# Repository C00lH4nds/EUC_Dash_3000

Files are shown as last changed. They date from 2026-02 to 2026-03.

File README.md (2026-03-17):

# EUC_Dash_3000
ESP32 based dashboard for BEGODE EUC.

WARNING: Works only with Begode A2!

Displays: current speed, wheel battery percentage, temperature, distance, onboard battery level, light status, connexion status.

Capture d'écran 2026-02-22 011819

Capture d'écran 2026-02-22 011900

Designed to be mounted on Gyroriderz glove.

Huge thanks to WheelAndroid for publishing BLE message coding (https://github.com/Wheellog/Wheellog.Android)

!!!WARNING!!!
Onboard battery can burn or explode if short circuited. Pay attention to connexions and waterthightness.
You might want to add a BMS to avoid risk.
As we are messing with the wheel BLE messages there is a tiny risk to generate a cut off.

BOM:
ESP32 C3 Supermini: https://fr.aliexpress.com/item/1005009040816248.html

0.96 inch OLED screen: https://fr.aliexpress.com/item/1005006141235306.html

3.3V buck&boost converter: https://fr.aliexpress.com/item/1005008602719818.html

Battery connectors: scavenge from broken gadget or from https://fr.aliexpress.com/item/4001192853672.html

18350 battery: https://www.lepetitvapoteur.com/fr/accus/8325-accu-mxjo-18350-700mah.html

M2 screws: https://fr.aliexpress.com/item/1005006187019546.html

Screen protector: scavenge from blister package

Heatshrink tubing

Electronic wires

Cyanoacrylate glue to secure tubing on the case

Neoprene glue for screen protector

TPU and PLA (or PETG)

Wiring diagram:

Capture d'écran 2026-02-17 215041

Component placement:

Capture d'écran 2026-02-22 011713

All components should lock in place. OLED screen uses four optional screws with printed washers.
Clip the two bottom pins of the switches.

Printed case:

Capture d'écran 2026-02-22 011242

Print in 0.2mm layers. No supports.
TPU parts have "TPU" prefix. Other parts can be printed in PLA or PETG.

Glue the screen protector to system case cover with neoprene glue. Make sure it is watertight.

Capture d'écran 2026-02-22 020949

Mount everytinhg, put the glove on, gently heat the honeycomb part with a heatgun and bend the button box so it rests on the top of your thumb joint (it is always better than printing with supports!)

Battery goes below the top strap. Don't set it too tight.

Left button: double beep.
Middle button: ON/OFF. hold 5 seconds to turn off (deepsleep mode). Wheel connection is automatic at startup or if connexion is lost.
Right button: light ON/OFF.

Happy ride!
Subscribe to my channel: https://www.youtube.com/@OIGLabs

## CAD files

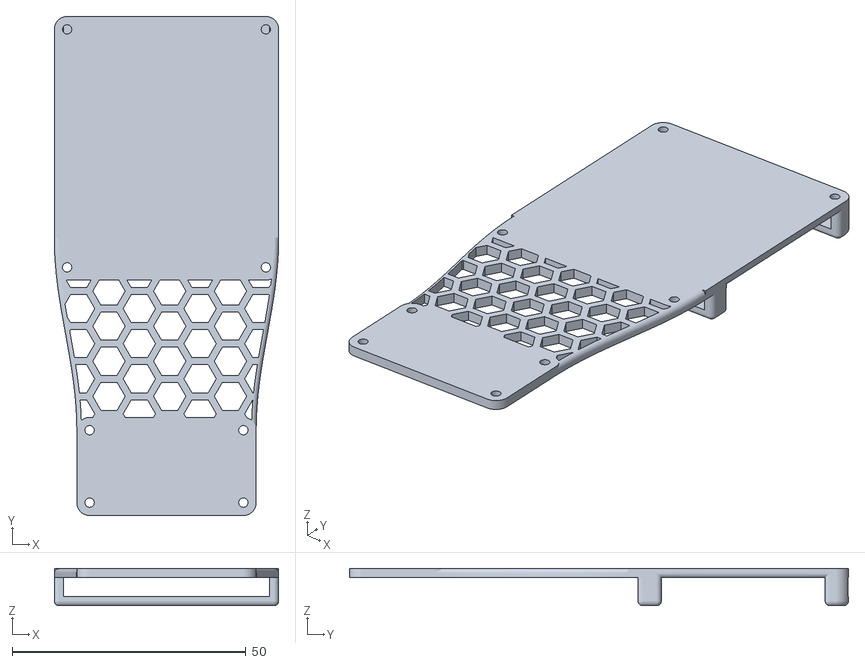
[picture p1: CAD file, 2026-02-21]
Stl/EUC Dash 3000_EUC Dash 3000 v37_System case_1_Support plate - straight.stl
48.0 x 106.7 x 8.00

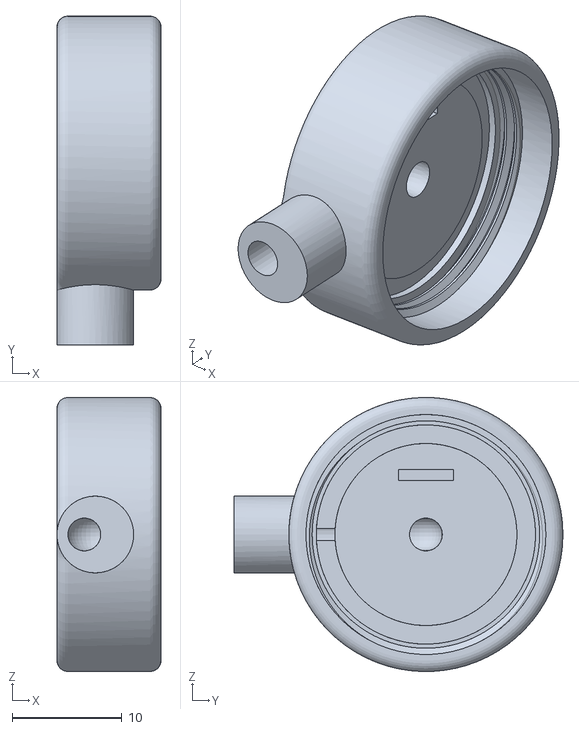
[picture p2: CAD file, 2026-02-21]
Stl/EUC Dash 3000_EUC Dash 3000 v37_Battery box_1_Battery box cap - negative.stl
9.50 x 30.0 x 25.0

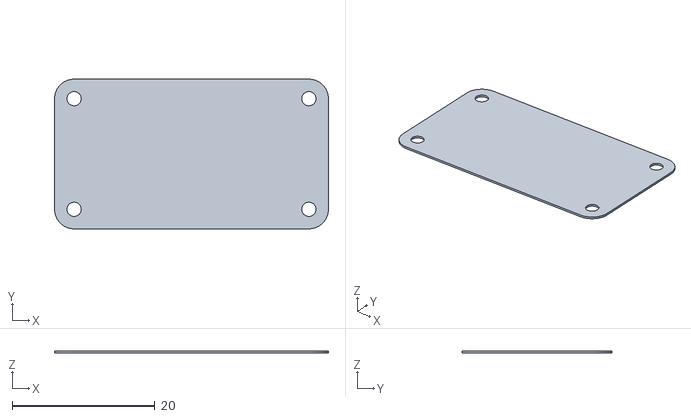
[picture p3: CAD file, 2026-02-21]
Stl/EUC Dash 3000_EUC Dash 3000 v37_Button box_1_TPU Button box gasket.stl
38.4 x 21.0 x 0.3

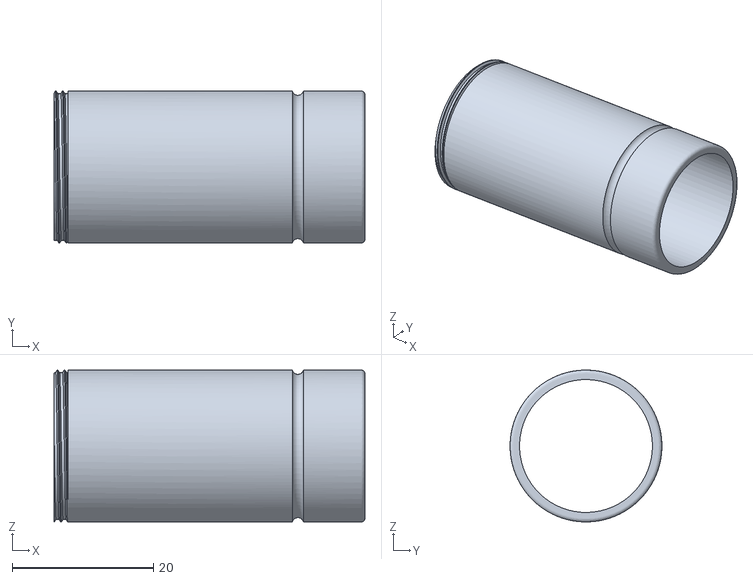
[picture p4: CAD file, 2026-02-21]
Stl/EUC Dash 3000_EUC Dash 3000 v37_Battery box_1_Battery box.stl
44.0 x 21.5 x 21.5

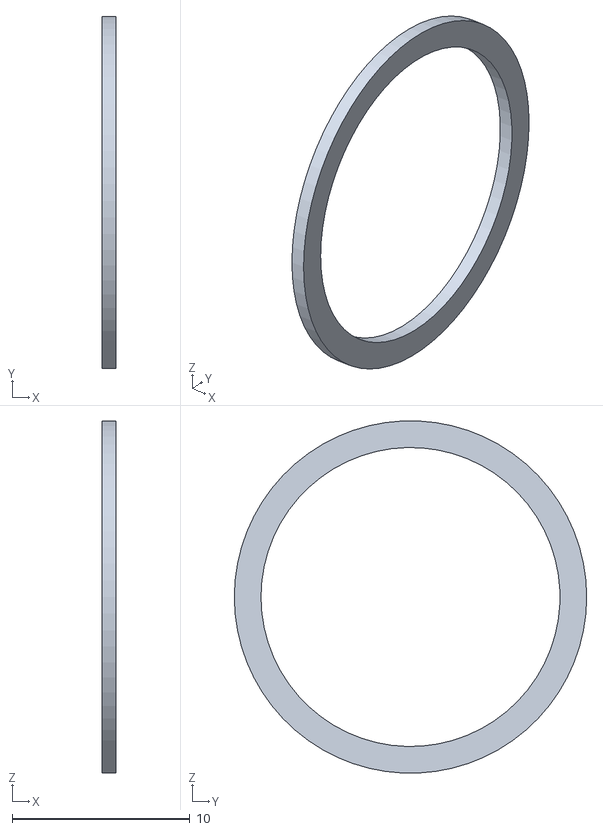
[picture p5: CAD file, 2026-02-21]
Stl/EUC Dash 3000_EUC Dash 3000 v37_Battery box_1_TPU gasket.stl
0.8 x 19.8 x 19.8

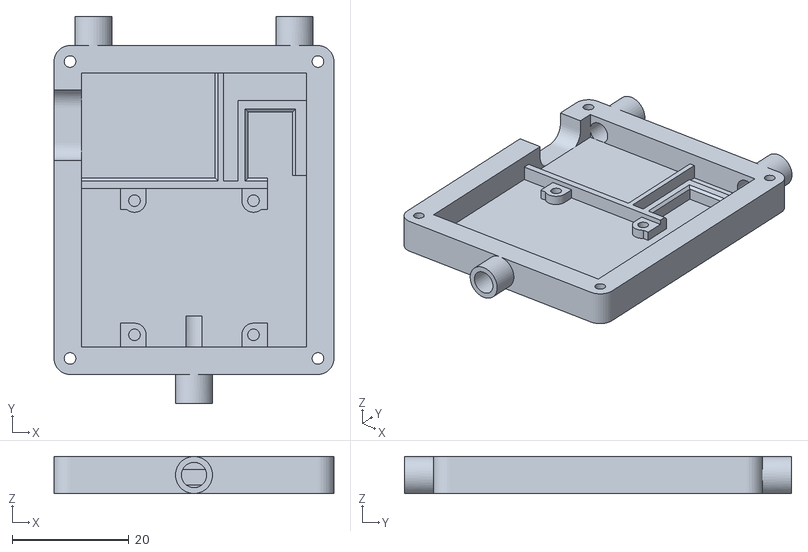
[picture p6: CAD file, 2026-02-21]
Stl/EUC Dash 3000_EUC Dash 3000 v37_System case_1_System box.stl
48.0 x 66.4 x 6.35

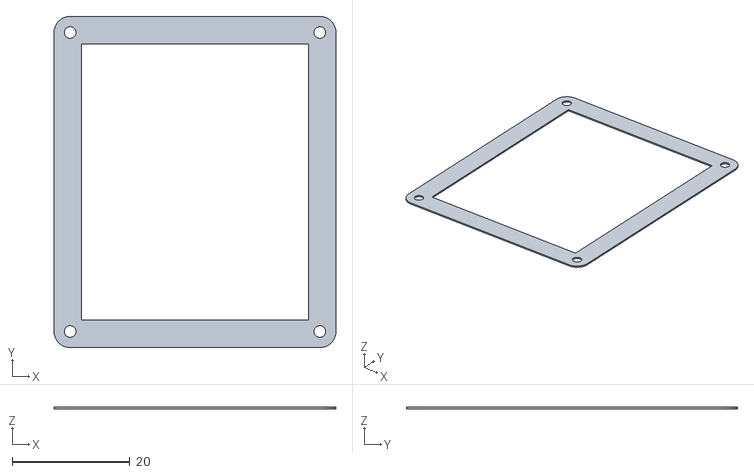
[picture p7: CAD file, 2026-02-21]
Stl/EUC Dash 3000_EUC Dash 3000 v37_System case_1_TPU System box gasket.stl
48.0 x 56.4 x 0.3

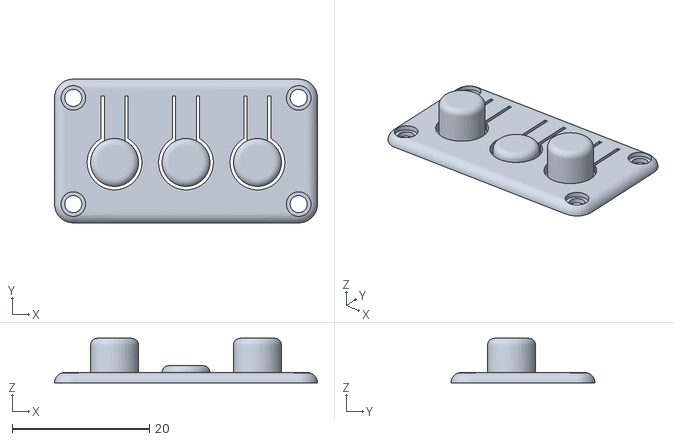
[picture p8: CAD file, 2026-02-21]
Stl/EUC Dash 3000_EUC Dash 3000 v37_Button box_1_Button box cover.stl
38.4 x 21.0 x 6.50

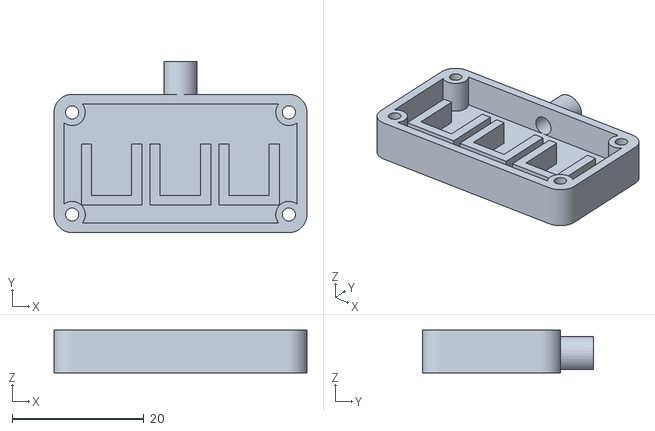
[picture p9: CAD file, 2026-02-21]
Stl/EUC Dash 3000_EUC Dash 3000 v37_Button box_1_Button box.stl
38.4 x 26.0 x 6.50

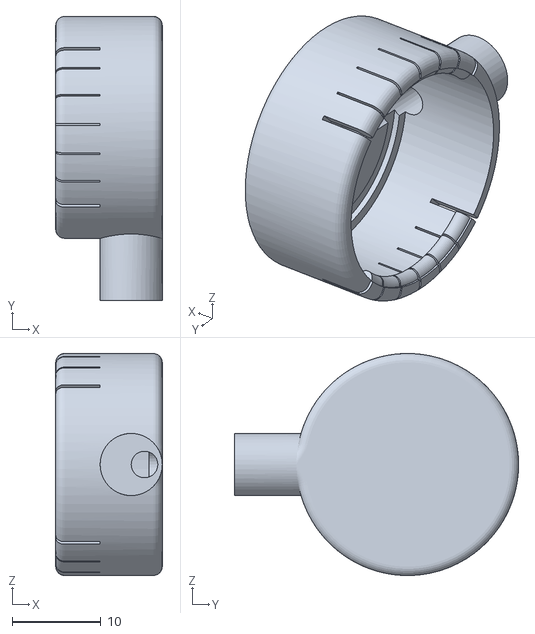
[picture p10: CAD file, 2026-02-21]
Stl/EUC Dash 3000_EUC Dash 3000 v37_Battery box_1_TPU Battery box cap - postive.stl
12.0 x 32.0 x 25.0

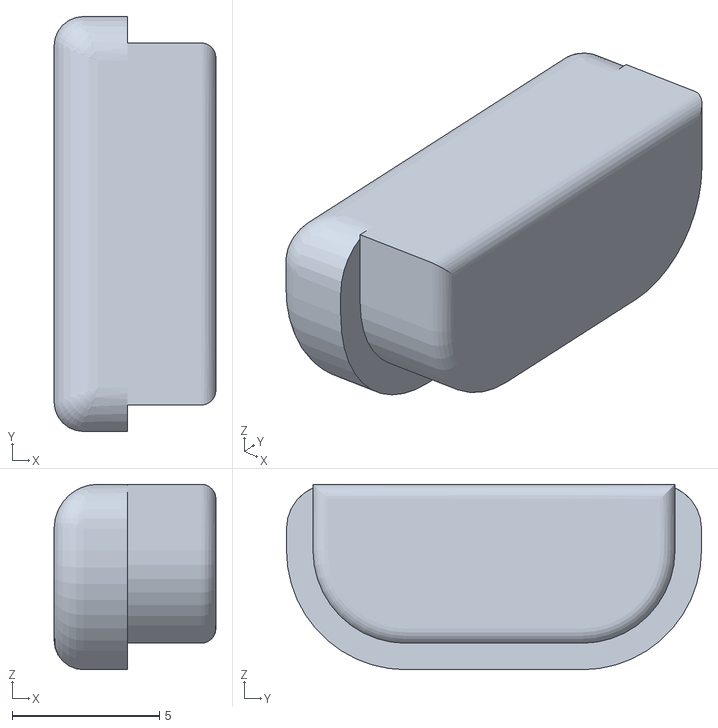
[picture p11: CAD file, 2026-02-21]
Stl/EUC Dash 3000_EUC Dash 3000 v37_System case_1_USB plug.stl
5.50 x 14.1 x 6.30

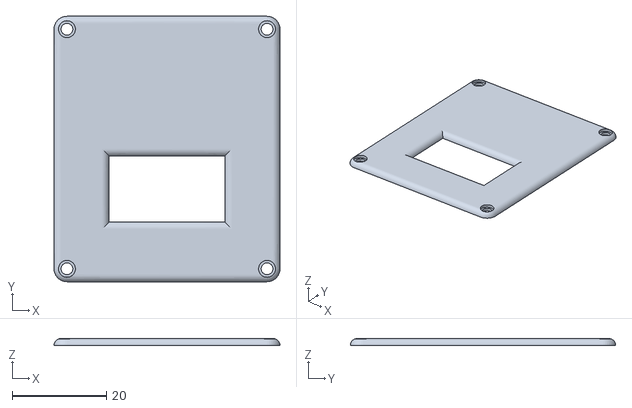
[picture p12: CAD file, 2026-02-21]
Stl/EUC Dash 3000_EUC Dash 3000 v37_System case_1_System box cover.stl
48.0 x 56.4 x 1.50

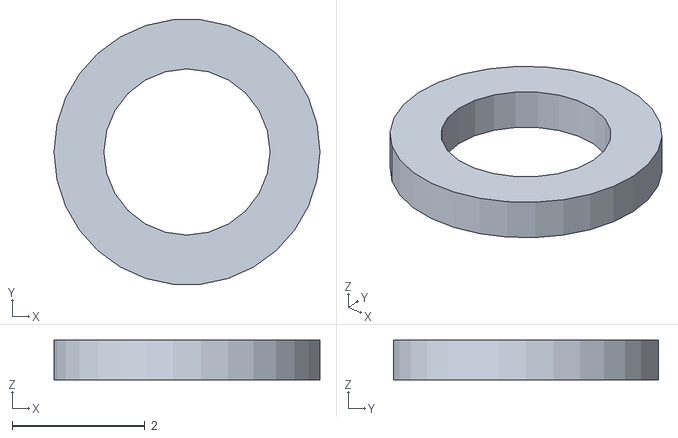
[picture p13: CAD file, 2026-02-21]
Stl/EUC Dash 3000_EUC Dash 3000 v37_System case_1_OLED Screen washer 3.stl
4.00 x 3.98 x 0.6

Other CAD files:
Stl/EUC Dash 3000_EUC Dash 3000 v37_System case_1_OLED Screen washer 1.stl
Stl/EUC Dash 3000_EUC Dash 3000 v37_System case_1_OLED Screen washer 4.stl
Stl/EUC Dash 3000_EUC Dash 3000 v37_System case_1_OLED Screen washer 2.stl

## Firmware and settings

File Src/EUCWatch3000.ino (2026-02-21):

#include <BLEDevice.h>
#include <BLEUtils.h>
#include <BLEScan.h>
#include <BLEAdvertisedDevice.h>
#include <BLEClient.h>
#include <Wire.h>
#include <Adafruit_GFX.h>
#include <Adafruit_SSD1306.h>

/* =====================================================
   OLED
   ===================================================== */
#define SCREEN_WIDTH 128
#define SCREEN_HEIGHT 64
#define OLED_RESET -1
Adafruit_SSD1306 display(SCREEN_WIDTH, SCREEN_HEIGHT, &Wire, OLED_RESET);

/* =====================================================
   PINS – ESP32-C3 MINI
   ===================================================== */
// (les pins ESP32 classiques sont commentés dans ta version d’origine)
/*
#define PIN_SDA 21
#define PIN_SCL 22
#define BTN_BEEP 13
#define BTN_LIGHT 14
#define BTN_POWER 4
#define BAT_ADC_PIN 34
*/

#define PIN_SDA 5
#define PIN_SCL 6
#define BTN_BEEP 7
#define BTN_LIGHT 8
#define BTN_POWER 2 // compatible wakeup
#define BAT_ADC_PIN 4 // ADC GPIO4

/* =====================================================
   POWER
   ===================================================== */
#define LONG_PRESS_MS 2000

unsigned long powerPressStart = 0;
bool powerBtnLastState = HIGH;
bool powerLongTriggered = false;
static unsigned long lastProgressDraw = 0;

/* =====================================================
   BLE – BEGODE A2
   ===================================================== */
static BLEUUID serviceUUID("0000ffe0-0000-1000-8000-00805f9b34fb");
static BLEUUID charUUID("0000ffe1-0000-1000-8000-00805f9b34fb");

BLEAdvertisedDevice* myDevice = nullptr;
BLEClient* pClient = nullptr;
BLERemoteCharacteristic* pRemoteCharacteristic = nullptr;

bool bleConnected = false;
bool telemetryValid = false;

unsigned long lastReconnectAttempt = 0;
unsigned long lastTelemetryTime = 0;

#define RECONNECT_INTERVAL_MS 2000
//#define TELEMETRY_TIMEOUT 5000

/* =====================================================
   BEEP
   ===================================================== */
#define BEEP_DELAY_MS 500
#define BEEP_COOLDOWN 1200
#define BEEP_SPEED_LIMIT_KMH 20.0 // Vitesse max autorisée pour le beep

uint8_t beepCmd[] = { 'b' };
unsigned long lastBeepAction = 0;

/* =====================================================
   LIGHT
   ===================================================== */
bool lightOn = false;
unsigned long lastLightBtnCheck = 0;
bool lastLightBtnState = HIGH;

uint8_t cmdLightOn[] = { 'Q' };
uint8_t cmdLightOff[] = { 'E' };

const uint8_t icon_headlight_16x16[] PROGMEM = { // Icone phare
  0xff, 0xff, 0xff, 0xff, 0xff, 0xff, 0xff, 0xff,
  0xff, 0x1f, 0x03, 0x43, 0xff, 0x79, 0x03, 0x7c,
  0xff, 0x7e, 0x03, 0x7c, 0xff, 0x79, 0x03, 0x43,
  0xff, 0x1f, 0xff, 0xff, 0xff, 0xff, 0xff, 0xff
};

/* =====================================================
   BATTERIES
   ===================================================== */
#define LOW_BATT_THRESHOLD 20
#define BLINK_INTERVAL_MS 500

bool blinkState = false;
unsigned long lastBlink = 0;

#define ACCU_MAX_V 4.20
#define ACCU_MIN_V 3.3

/* =====================================================
   TELEMETRY
   ===================================================== */
float speed_kmh = 0.0;
float voltage = 0.0;
int batteryWheel = 0;
int batteryAccu = 0;
int temp_c = 0;
float distance_km = 0.0;

/* =====================================================
   POWER
   ===================================================== */
void goToDeepSleep() {
  display.clearDisplay();
  display.display();

#if CONFIG_IDF_TARGET_ESP32C3
  esp_deep_sleep_enable_gpio_wakeup(1ULL << BTN_POWER, ESP_GPIO_WAKEUP_GPIO_LOW);
#else
  esp_sleep_enable_ext0_wakeup((gpio_num_t)BTN_POWER, 0);
#endif

  esp_deep_sleep_start();
}

/* =====================================================
   UTILS
   ===================================================== */
int readAccuPercent() {
  long sum = 0;
  for (int i = 0; i < 5; i++) {
    sum += analogRead(BAT_ADC_PIN);
    delay(2);
  }

  float raw = sum / 5.0;
  float v_bat = 0.0014 * raw + 0.0668;
  //Serial.print("raw: ");Serial.print(raw);Serial.print(" v_bat: ");Serial.println(v_bat);
  int pct = (v_bat - ACCU_MIN_V) * 100 / (ACCU_MAX_V - ACCU_MIN_V);
  return constrain(pct, -1, 100);
}

/* =====================================================
   GOTWAY / BEGODE PROTOCOL HANDLER
   ===================================================== */
class GotwayUnpacker {
public:
  enum State { UNKNOWN, COLLECTING, DONE };
  State state = UNKNOWN;

  uint8_t buffer[24];
  int pos = 0;
  int oldc = -1;

  bool addChar(uint8_t c) {
    if (state == COLLECTING) {
      buffer[pos++] = c;

      if (pos == 24) {
        state = DONE;
        return true;
      }

      if (pos > 20 && c != 0x5A) { // invalid footer
        state = UNKNOWN;
        pos = 0;
      }
    } else {
      if (c == 0xAA && oldc == 0x55) {
        buffer[0] = 0x55;
        buffer[1] = 0xAA;
        pos = 2;
        state = COLLECTING;
      }
      oldc = c;
    }
    return false;
  }

  void reset() {
    state = UNKNOWN;
    pos = 0;
  }
};

GotwayUnpacker unpacker;

void parseFrame(uint8_t* buff) {
  uint8_t type = buff[18];

  if (type == 0x00) {
    // Frame A: live telemetry

    // --- Speed ---
    int16_t speed_raw = (buff[4] << 8) | buff[5]; // Big Endian
    speed_kmh = speed_raw * 3.6 / 100.0;          // raw to km/h

    // --- Temperature ---
    // Ici on suppose MPU6050, sinon adapter si c'est MPU6500
    int16_t temp_raw = (int16_t)((buff[12] << 8) | buff[13]); // Big Endian
    temp_c = ((float)temp_raw / 340.0f) + 36.53f;

    // --- Voltage & Battery ---
    uint16_t voltage_raw = (buff[2] << 8) | buff[3]; // Big Endian
    voltage = voltage_raw / 100.0f;                  // en volts

    // Calcul du % batterie selon le code Android
    if (voltage_raw > 6680) {
      batteryWheel = 100;
    } else if (voltage_raw > 5440) {
      batteryWheel = (int)round((voltage_raw - 5320) / 13.6);
    } else if (voltage_raw > 5120) {
      batteryWheel = (voltage_raw - 5120) / 36;
    } else {
      batteryWheel = 0;
    }

    // ---------- DISTANCE ----------
    uint16_t distance_m = (buff[8] << 8) | buff[9];
    distance_km = distance_m / 1000.0f;

    // --- Telemetry valid ---
    telemetryValid = true;
    lastTelemetryTime = millis();
  }
}

/* =====================================================
   BLE NOTIFY CALLBACK
   ===================================================== */
class MyNotifyCallback {
public:
  static void notifyCallback(BLERemoteCharacteristic* pBLERemoteCharacteristic,
                             uint8_t* pData, size_t length, bool isNotify) {
    /*
    // --- DEBUG: afficher la trame entière ---
    Serial.print("Trame: ");
    for (int i = 0; i < length; i++) {
      Serial.print(i);
      Serial.print(":");
      if (pData[i] < 16) Serial.print("0");
      Serial.print(pData[i], HEX);
      Serial.print(" ");
    }
    Serial.println();
    */

    for (size_t i = 0; i < length; i++) {
      if (unpacker.addChar(pData[i])) {
        parseFrame(unpacker.buffer);
        unpacker.reset();
      }
    }
  }
};

/* =====================================================
   BLE SCAN CALLBACK
   ===================================================== */
class MyAdvertisedDeviceCallbacks : public BLEAdvertisedDeviceCallbacks {
  void onResult(BLEAdvertisedDevice advertisedDevice) {
    if (advertisedDevice.haveServiceUUID() &&
        advertisedDevice.isAdvertisingService(serviceUUID)) {
      myDevice = new BLEAdvertisedDevice(advertisedDevice);
      BLEDevice::getScan()->stop();
    }
  }
};

MyAdvertisedDeviceCallbacks advCallbacks;

/* =====================================================
   BLE CONNECT / DISCONNECT
   ===================================================== */
bool connectToWheel() {
  if (!myDevice) return false;

  pClient = BLEDevice::createClient();
  if (!pClient->connect(myDevice)) return false;

  BLERemoteService* pService = pClient->getService(serviceUUID);
  if (!pService) return false;

  pRemoteCharacteristic = pService->getCharacteristic(charUUID);
  if (!pRemoteCharacteristic) return false;

  if (pRemoteCharacteristic->canNotify()) {
    pRemoteCharacteristic->registerForNotify(MyNotifyCallback::notifyCallback);
  }

  bleConnected = true;
  telemetryValid = false;
  return true;
}

void handleBleDisconnect() {
  bleConnected = false;
  telemetryValid = false;
  lightOn = false;

  if (pClient) {
    pClient->disconnect();
    delete pClient;
    pClient = nullptr;
  }

  myDevice = nullptr;
}

/* =====================================================
   BEEP
   ===================================================== */
void sendDoubleBeep() {
  if (!bleConnected) return;
  pRemoteCharacteristic->writeValue(beepCmd, sizeof(beepCmd), false);
  delay(BEEP_DELAY_MS);
  pRemoteCharacteristic->writeValue(beepCmd, sizeof(beepCmd), false);
}

void sendSingleBeep() {
  if (!bleConnected) return;
  pRemoteCharacteristic->writeValue(beepCmd, sizeof(beepCmd), false);
}

/* =====================================================
   LIGHT
   ===================================================== */
void setLight(bool on) {
  if (!bleConnected) return;

  if (on) {
    pRemoteCharacteristic->writeValue(cmdLightOn, sizeof(cmdLightOn), false);
  } else {
    pRemoteCharacteristic->writeValue(cmdLightOff, sizeof(cmdLightOff), false);
  }
  // Beep simple
  // sendSingleBeep();
}

/* =====================================================
   DISPLAY
   ===================================================== */
void drawPowerProgress(unsigned long elapsed) {
  display.clearDisplay();
  display.setTextColor(SSD1306_WHITE);
  display.setTextSize(1);

  String text = "HOLD TO TURN OFF";

  int textWidth = text.length() * 6 * 1;
  int textHeight = 8 * 1;

  int barWidth = 100;
  int barHeight = 10;
  int spacing = 8;

  int totalHeight = textHeight + spacing + barHeight;
  int startY = (SCREEN_HEIGHT - totalHeight) / 2;

  int textX = (SCREEN_WIDTH - textWidth) / 2;
  int textY = startY;

  display.setCursor(textX, textY);
  display.print(text);

  int barX = (SCREEN_WIDTH - barWidth) / 2;
  int barY = textY + textHeight + spacing;

  display.drawRect(barX, barY, barWidth, barHeight, SSD1306_WHITE);

  int fill = map(elapsed, 0, LONG_PRESS_MS, 0, barWidth - 2);
  fill = constrain(fill, 0, barWidth - 2);

  display.fillRect(barX + 1, barY + 1, fill, barHeight - 2, SSD1306_WHITE);
  display.display();
}

void drawBatteryBar(int x, int y, int w, int h, int percent) {
  display.drawRect(x, y, w, h, SSD1306_WHITE);
  int fill = (w - 2) * percent / 100;
  display.fillRect(x + 1, y + 1, fill, h - 2, SSD1306_WHITE);
}

unsigned long lastDisplayUpdate = 0;
#define DISPLAY_INTERVAL 150

// Affiche °C à la position (x, y)
void printDegC(int x, int y) {
  display.setCursor(x + 18, y + 2); // le C
  display.print("C");
  display.drawCircle(x + 14, y + 2, 2, SSD1306_WHITE); // le °
}

void showOffScreen() {
  display.clearDisplay();
  display.setTextSize(4);

  String txt = "OFF";
  int textWidth = txt.length() * 6 * 4;
  int x = (SCREEN_WIDTH - textWidth) / 2;
  int y = (SCREEN_HEIGHT - 8 * 4) / 2;

  display.setCursor(x, y);
  display.print(txt);
  display.display();
}

void updateDisplay() {
  unsigned long now = millis();

  if (now - lastBlink > BLINK_INTERVAL_MS) {
    blinkState = !blinkState;
    lastBlink = now;
  }

  batteryAccu = readAccuPercent();
  bool lowBattWheel = telemetryValid && (batteryWheel <= LOW_BATT_THRESHOLD);

  display.clearDisplay();
  display.setTextColor(SSD1306_WHITE);

  /* ================= TOP ================= */
  // Batterie roue (haut gauche)
  display.setTextSize(2);
  display.setCursor(0, 0);
  if (telemetryValid) display.print(batteryWheel);
  else display.print("--");
  display.print("%");

  // Température (haut droite)
  display.setTextSize(2);
  int tempX = SCREEN_WIDTH - 52; // ajusté pour tenir "°C"
  display.setCursor(tempX, 0);
  if (telemetryValid) display.print(temp_c);
  else display.print("--");
  printDegC(tempX + 16, 0); // °C à droite du chiffre

  /* ================= SPEED ================= */
  int speedDisp = telemetryValid ? abs((int)round(speed_kmh)) : 0;

  char speedStr[3];
  snprintf(speedStr, sizeof(speedStr), "%02d", speedDisp);

  display.setTextSize(4);

  int textSize = 4;
  int charWidth = 6 * textSize;
  int speedWidth = charWidth * 2;
  int speedX = (SCREEN_WIDTH - speedWidth) / 2;
  int speedY = 18;

  display.setCursor(speedX, speedY);
  display.print(speedStr);

  // Label km/h
  display.setTextSize(1);
  int kmhX = speedX + speedWidth + 4;
  int kmhY = speedY + (4 * 8 - 8) / 2;
  display.setCursor(kmhX, kmhY);
  display.print("km/h");

  /* ================= LIGHT ================= */
  int iconX = speedX - 36;
  int iconY = speedY + 8;

  if (lightOn) {
    display.drawBitmap(iconX, iconY, icon_headlight_16x16, 16, 16, SSD1306_WHITE);
  }

  /* ================= DISTANCE ================= */
  display.setTextSize(1);
  display.setCursor(0, SCREEN_HEIGHT - 8);
  if (telemetryValid) {
    display.print(distance_km, 1);
  } else {
    display.print("--.-");
  }
  display.print("km");

  /* ================= STATUS ================= */
  display.setTextSize(1);
  String status;
  if (!bleConnected) status = "OFFLINE";
  else if (lowBattWheel) status = "!!!LOW BATTERY!!!";
  else status = "ONLINE";

  int16_t statusX = (SCREEN_WIDTH - status.length() * 6) / 2;
  display.setCursor(statusX, 55);
  display.print(status);

  /* ================= ESP BATTERY ================= */
  int barCount = map(batteryAccu, 0, 90, 1, 5);
  int barW = 3;
  int barH = 8;
  int gap = 2;
  int baseX = SCREEN_WIDTH - (barW * 5 + gap * 4) - 2;
  int baseY = SCREEN_HEIGHT - barH - 2;

  if (batteryAccu < 0) {
    if (blinkState) {
      display.drawRect(baseX, baseY, barW * 5 + gap * 4, barH, SSD1306_WHITE);
    }
  } else {
    for (int i = 0; i < barCount; i++) {
      int x = baseX + i * (barW + gap);
      display.fillRect(x, baseY, barW, barH, SSD1306_WHITE);
    }
  }

  display.display();
}

/* =====================================================
   SETUP
   ===================================================== */
void setup() {
  Serial.begin(115200);

  pinMode(BTN_BEEP, INPUT_PULLUP);
  pinMode(BTN_LIGHT, INPUT_PULLUP);
  pinMode(BTN_POWER, INPUT_PULLUP);

  analogReadResolution(12); // 0-4095

  Wire.begin(PIN_SDA, PIN_SCL);

  display.begin(SSD1306_SWITCHCAPVCC, 0x3C);
  display.clearDisplay();
  display.display();

  BLEDevice::init("ESP32-Begode");
}

/* =====================================================
   LOOP
   ===================================================== */
unsigned long lastBtnCheck = 0;
bool lastBtnState = HIGH;
#define DEBOUNCE_MS 50

void loop() {
  unsigned long now = millis();

  bool powerState = digitalRead(BTN_POWER);

  // Détection appui
  if (powerBtnLastState == HIGH && powerState == LOW) {
    powerPressStart = millis();
    powerLongTriggered = false;
  }

  // ================= POWER HOLD =================
  if (powerState == LOW) {
    if (!powerLongTriggered) {
      unsigned long heldTime = millis() - powerPressStart;

      if (now - lastProgressDraw > 30) {
        drawPowerProgress(heldTime);
        lastProgressDraw = now;
      }

      if (heldTime >= LONG_PRESS_MS) {
        powerLongTriggered = true;
        showOffScreen();
        delay(1000);
        goToDeepSleep();
      }
    }

    powerBtnLastState = powerState;
    return;
  }

  // Relâchement avant 2s → retour affichage normal
  if (powerBtnLastState == LOW && powerState == HIGH) {
    if (!powerLongTriggered) {
      updateDisplay();
    }
  }

  powerBtnLastState = powerState;

  // Déconnexion BLE
  if (bleConnected && pClient && !pClient->isConnected()) {
    handleBleDisconnect();
  }

  // Timeout télémétrie - désactivé car affiche des dashs alors que tout va bien
 /* if (telemetryValid && now - lastTelemetryTime > TELEMETRY_TIMEOUT) {
    telemetryValid = false;
  }*/

  // Reconnexion BLE
  if (!bleConnected && !pClient && now - lastReconnectAttempt > RECONNECT_INTERVAL_MS) {
    lastReconnectAttempt = now;

    BLEScan* scan = BLEDevice::getScan();
    scan->setAdvertisedDeviceCallbacks(&advCallbacks);
    scan->setActiveScan(true);
    scan->start(3, false);

    if (myDevice) connectToWheel();
  }

  // Bouton BEEP (debounce)
  if (now - lastBtnCheck > DEBOUNCE_MS) {
    bool btn = digitalRead(BTN_BEEP);

    if (lastBtnState == HIGH && btn == LOW) {
      if (now - lastBeepAction > BEEP_COOLDOWN && abs(speed_kmh) < BEEP_SPEED_LIMIT_KMH) {
        lastBeepAction = now;
        sendDoubleBeep();
      }
    }

    lastBtnState = btn;
    lastBtnCheck = now;
  }

  // Bouton phare (toggle ON / OFF)
  if (now - lastLightBtnCheck > DEBOUNCE_MS) {
    bool btn = digitalRead(BTN_LIGHT);

    if (lastLightBtnState == HIGH && btn == LOW) {
      lightOn = !lightOn;
      setLight(lightOn);
    }

    lastLightBtnState = btn;
    lastLightBtnCheck = now;
  }

  // Affichage
  if (now - lastDisplayUpdate > DISPLAY_INTERVAL) {
    lastDisplayUpdate = now;
    updateDisplay();
  }
}

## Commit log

2026-02-22 Expand README with project details and warnings
    Added detailed project information, warnings, and BOM links.
2026-02-22 Update README with assembly instructions and warnings
    Added warnings, component details, and assembly instructions.
2026-02-22 Update README with BOM and wiring diagram
    Added additional BOM items and wiring diagram.
2026-02-22 Update README with additional assembly instructions
    Added images and details for wiring diagram, component placement, and printed case instructions.
2026-02-22 Enhance README with additional display and button info
    Updated the README to include light status and connection status in the display information. Added button functionalities for the left, middle, and right buttons.
2026-02-22 Add instruction for clipping switch pins
    Added instruction to clip the two bottom pins of the switches.
